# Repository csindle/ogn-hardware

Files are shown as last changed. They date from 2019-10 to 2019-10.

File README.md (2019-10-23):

# Open Glider Network Receiver Station Hardware (PipePi)

This project shows a concrete implementation of the ideas and goals on the 
[Open Glider Network](https://www.glidernet.org/) wiki page discussing how to build an 
[OGN receiver](http://wiki.glidernet.org/ogn-receiver-hardware-and-software#hardware).

Below is my current reference design which incorporates more than 12 receiver-years'
worth of experience.
The receivers are located outdoors, in the moderately harsh environment of the Western Cape,
South Africa.

#### Goals:

1. **Far range:** Minimise Radio Frequency (RF) path losses, and noise introduction.
1. **Affordable:** Few, low-cost components, and some cheap building supplies.
1. **Simple:** Largely plug-and-play components.  No RF soldering, or coax-ground loops.
1. **Reliable:**  Standards compliant electronics, DIY casing.

The CAD files for the below diagrams are in their respective directories.

All dimensions are in millimetres.

# Bill of Materials

Item   | Description
---: | :---
Raspberry Pi | Version 3B, 3B+, or 4
FlightAware USB	| With built-in Low Noise Amplifier (LNA), but without the 1090 MHz bandpass filter
SD card | 8 GB, or greater
Backplane | See description below
Outdoor Enclosure | See description below
PoE splitter | Active, standards compliant (IEEE 802.3af)
Antenna-to-SDR adaptor | Male N-type to male SMA adaptor
Antenna | 868 Mhz depending on your location. Available online from China.
PoE injector | Active, standards compliant (IEEE 802.3af)
Ethernet cable | Rated for outdoor usage
Cable/zip-ties | width less than 5 mm

# Backplane

##### Material: ~3 mm plywood, with ~5 mm drilled holes.

The Raspberry Pi and other components are mounted upon the backplane.
It provides strain relief, and durability due to its rigidity.

One may be tempted to drill only those holes that are immediately required, but in my experience,
a re-configurable backplane, decoupled from the immediate components choice, is a better long-term solution.
For example, the Raspberry Pi 4 upgrade swapped the USB and Ethernet positions,
implying that the lower holes [only!] now need to be mirrored.
A drill shouldn't be needed to swap out a RPi3 for a RPi4.

Other rigid, non-conductive material may be used instead of wood.

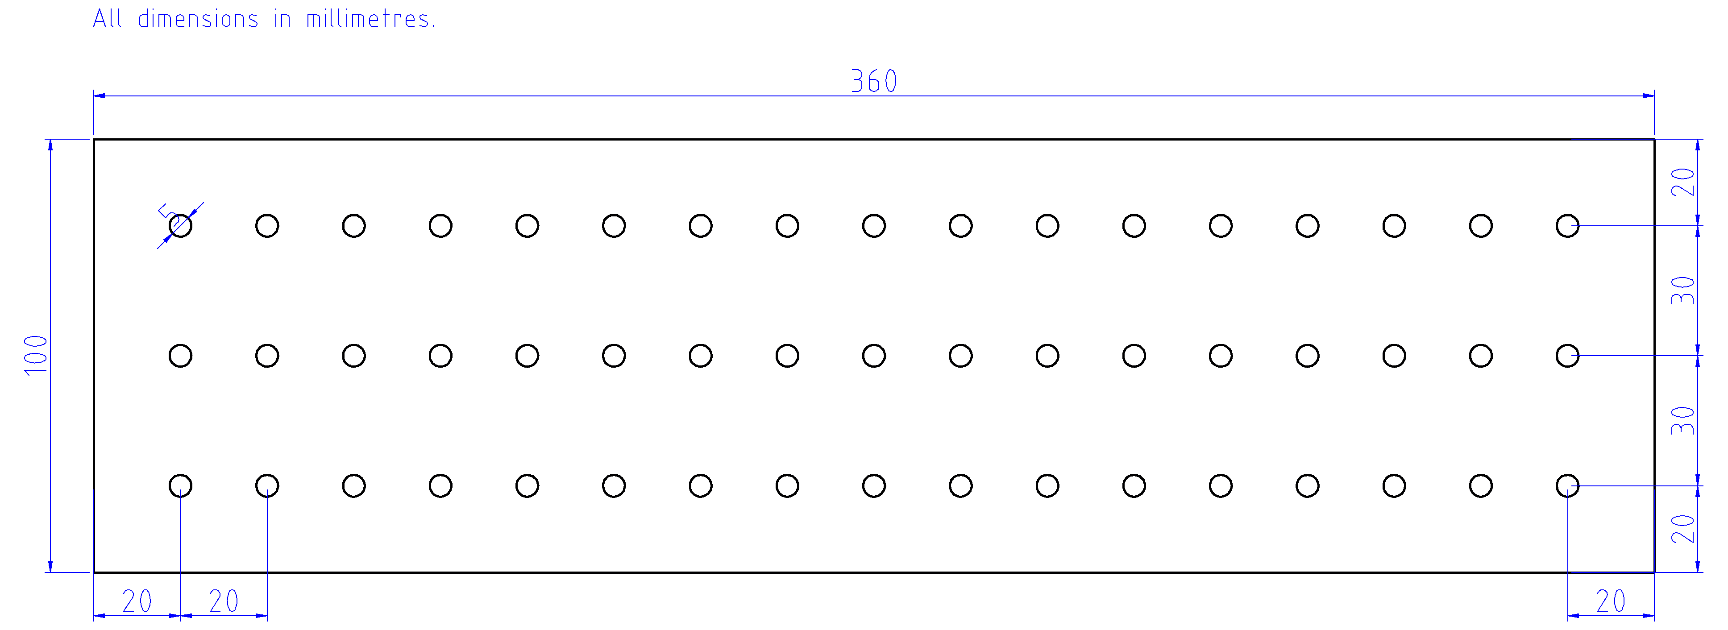
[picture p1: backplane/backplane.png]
Wooden backplane


# Weather-proof Outdoor Enclosure
##### Material: white, 110 mm PVC pipe, and matching commercial, off-the-shelf plumbing end-cap.

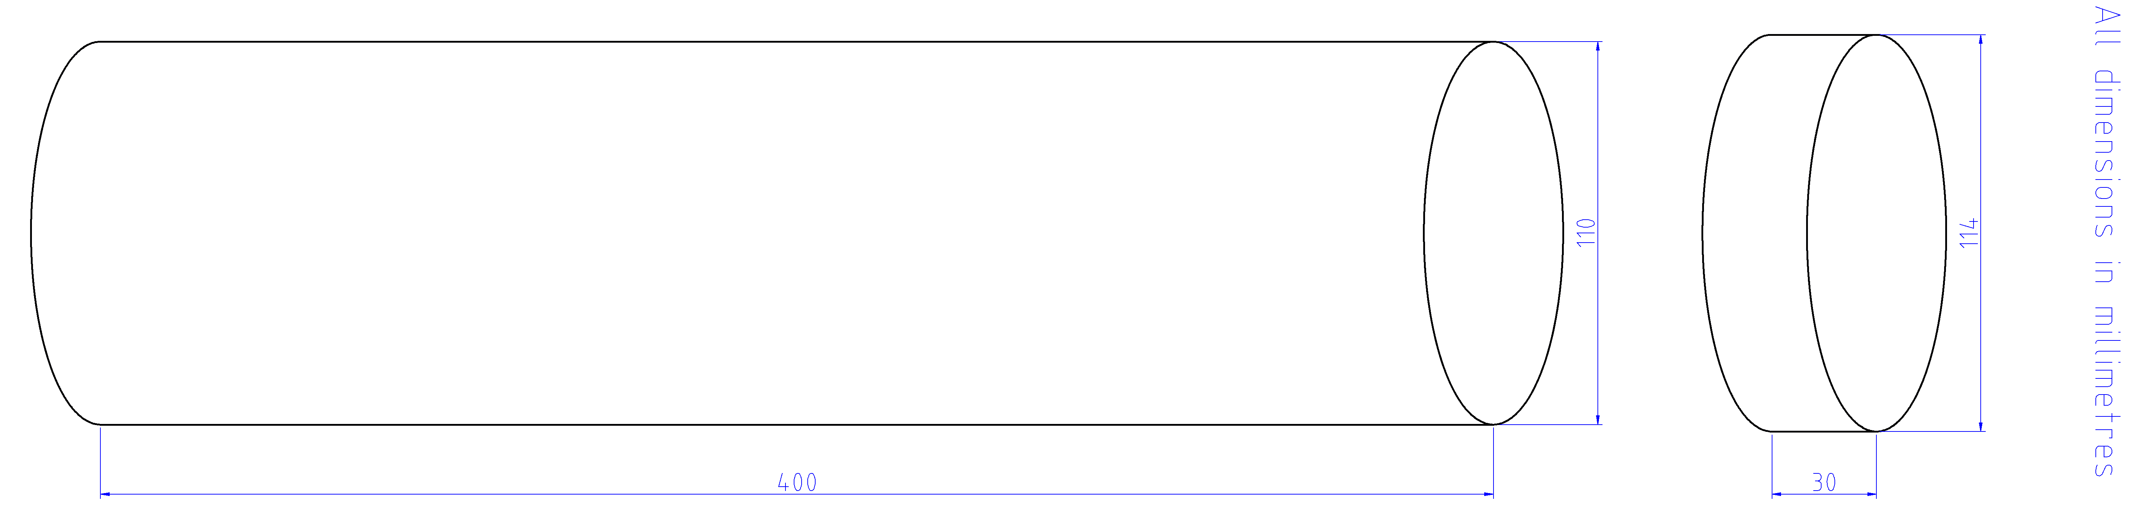
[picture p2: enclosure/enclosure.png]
PVC pipe enclosure


Unless the end-cap is holding up the enclosure (on, say, an internal mounting),
it stays on tightly enough without adhesive being required, which makes future upgrades easier.

# Assembly

Raspberry Pi cable-tied to backplane and installed within the enclosure.

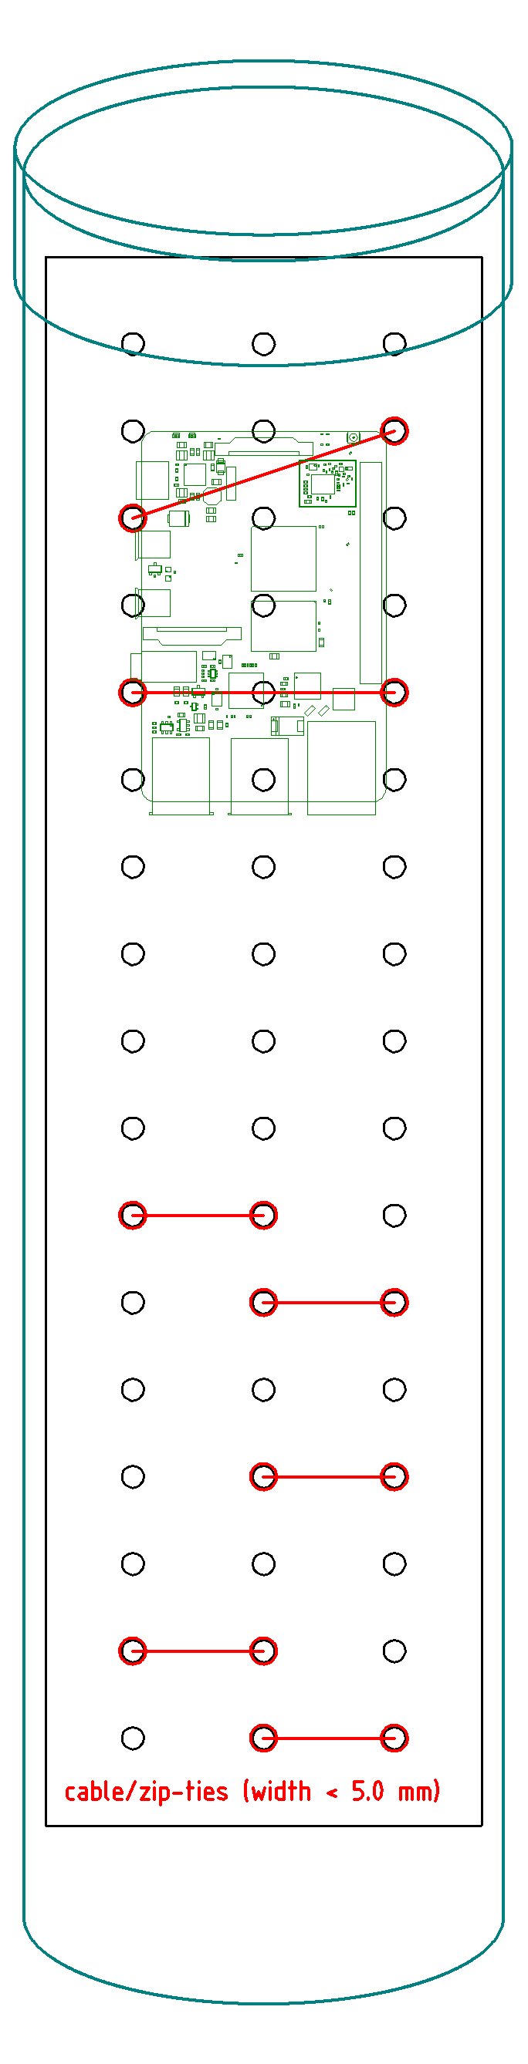
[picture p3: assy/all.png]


Parts not shown in CAD drawing:

* PoE splitter, with 5V USB power output (RPi4 requires Type-C plug, the rest, micro-USB)
* Ethernet cable
* FlightAware USB RTL SDR
* Male N-type to male SMA connector (one piece, not a pig-tail)
* Antenna cable

# Receiver's Internal Components
Assembling and securing the internal components.
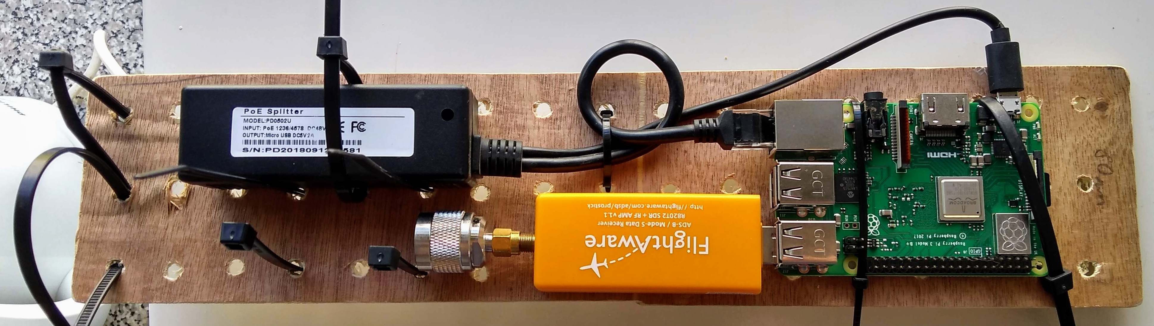
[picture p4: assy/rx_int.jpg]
Receiver components


# Receiver Mounted
Final installation, as high up as possible.
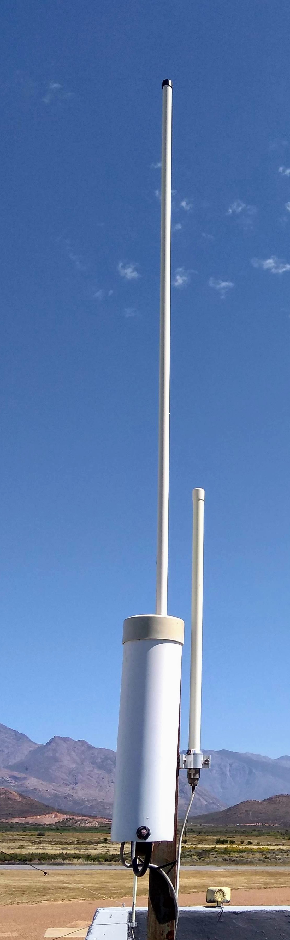
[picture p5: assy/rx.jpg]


# Thanks

To [PicoJump](https://www.picojump.com) for providing remote SSH and HTTP access, and up-time monitoring.

Please contact me, or open an issue, if you have any questions or suggestions.

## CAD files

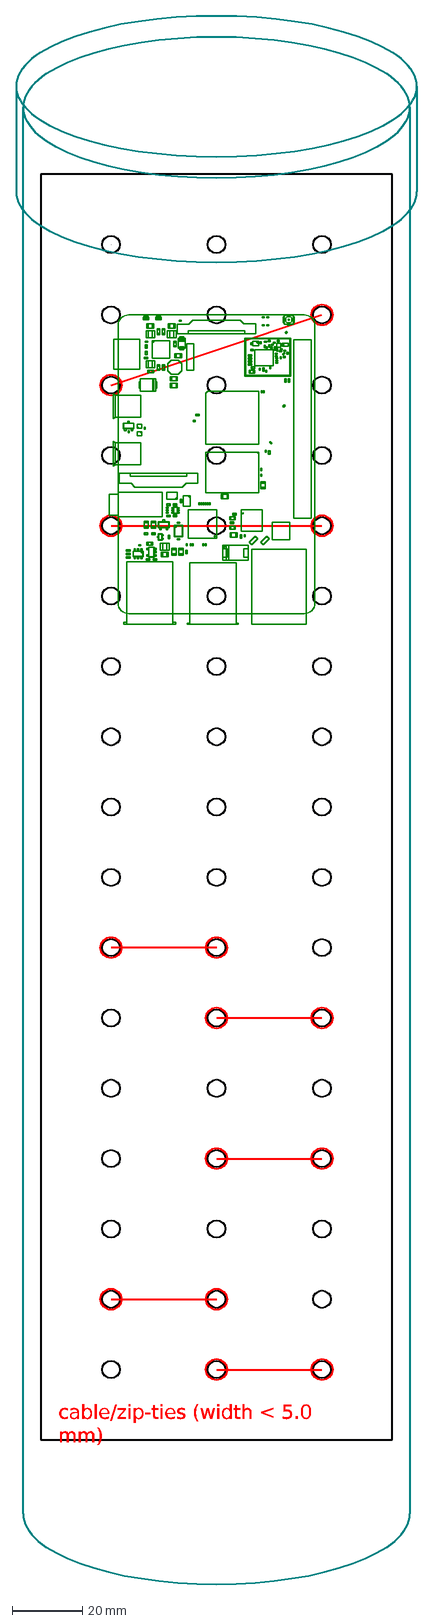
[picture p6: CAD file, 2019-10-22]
assy/all.dxf
cable/zip-ties (width < 5.0 mm)

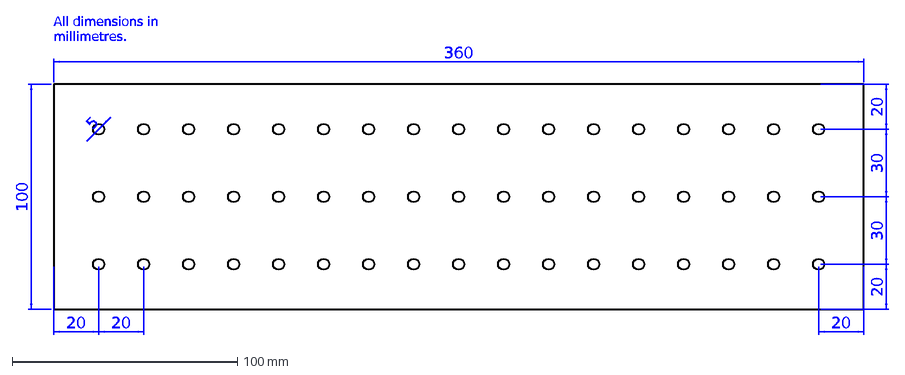
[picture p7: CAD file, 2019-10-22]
backplane/backplane.dxf
360
100
20
30
5
All dimensions in millimetres.

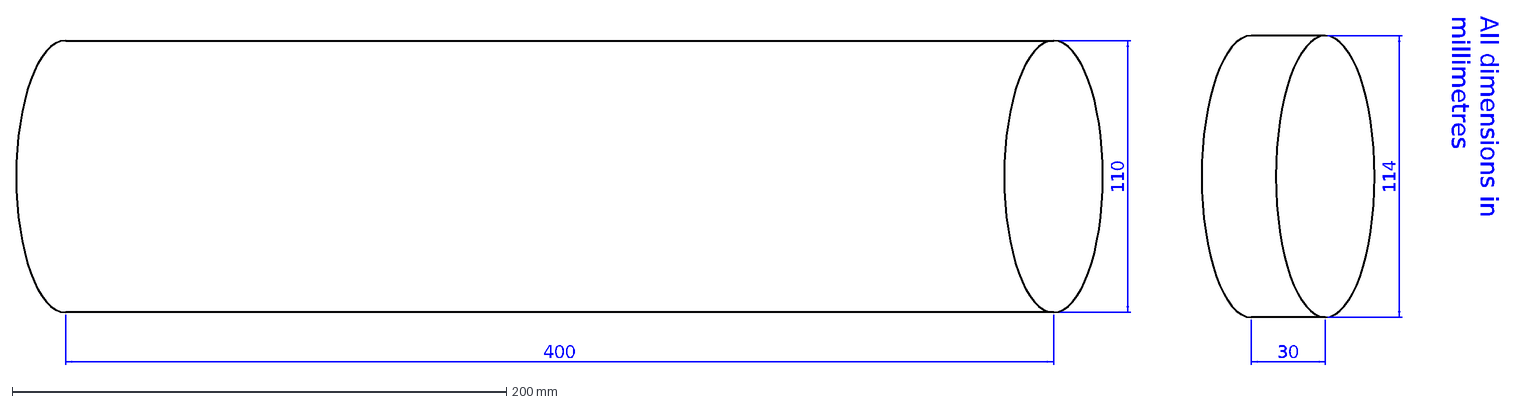
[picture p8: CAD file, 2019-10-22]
enclosure/enclosure.dxf
110
30
114
400
All dimensions in millimetres

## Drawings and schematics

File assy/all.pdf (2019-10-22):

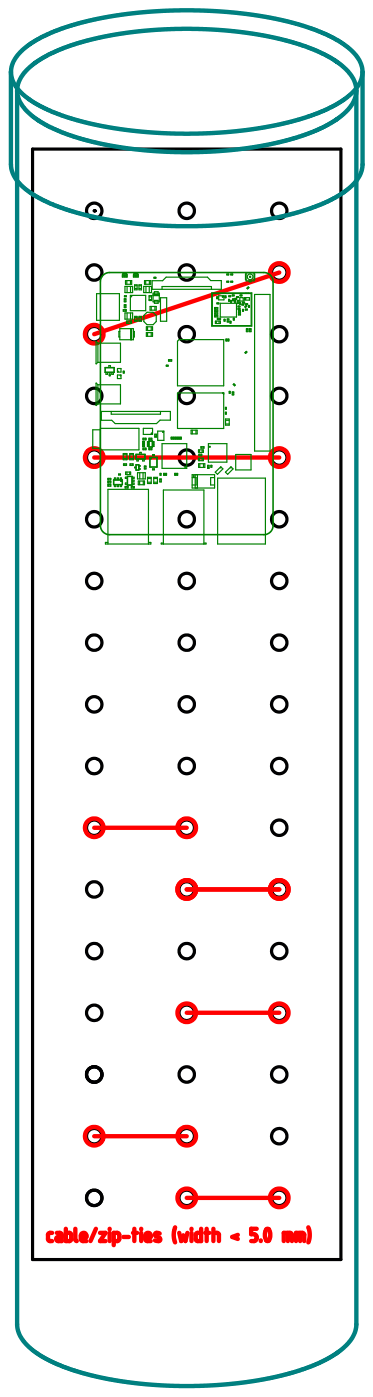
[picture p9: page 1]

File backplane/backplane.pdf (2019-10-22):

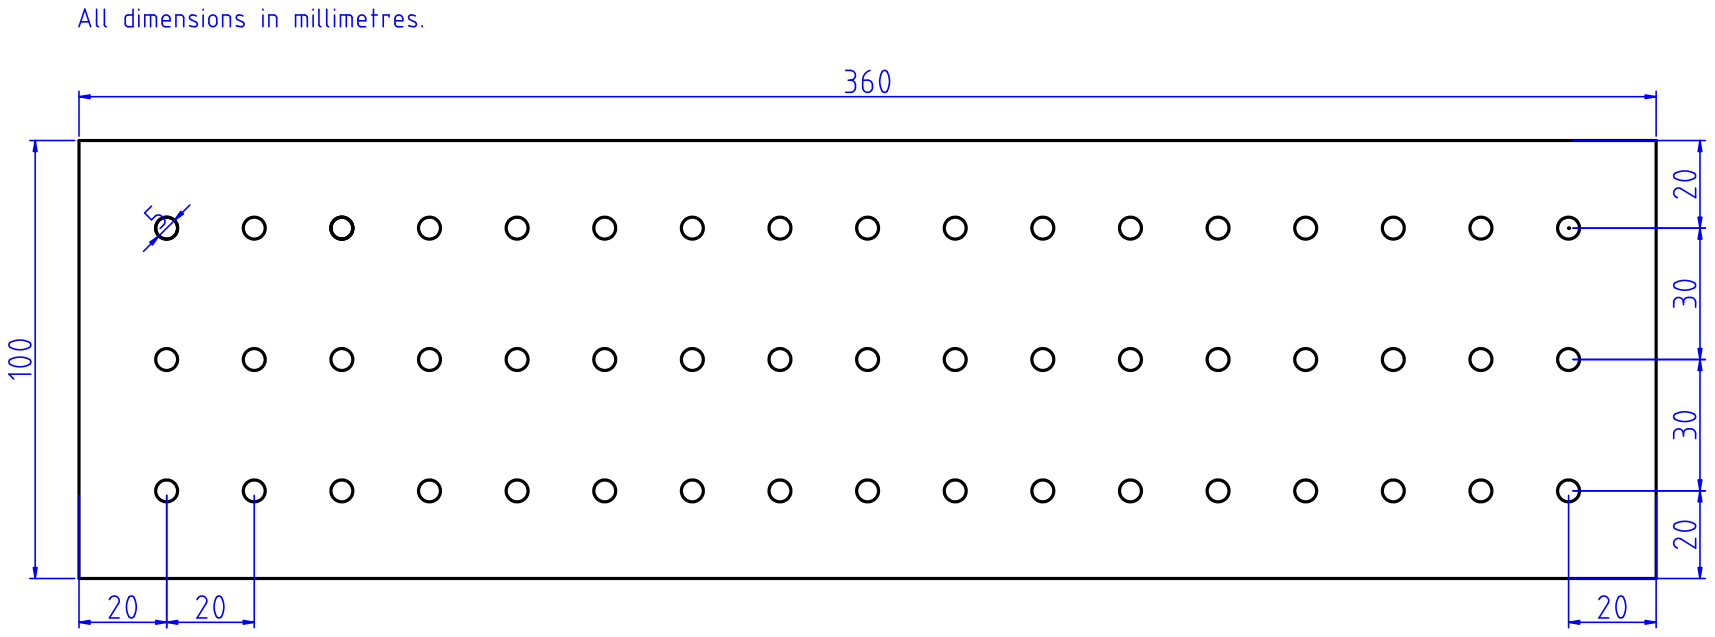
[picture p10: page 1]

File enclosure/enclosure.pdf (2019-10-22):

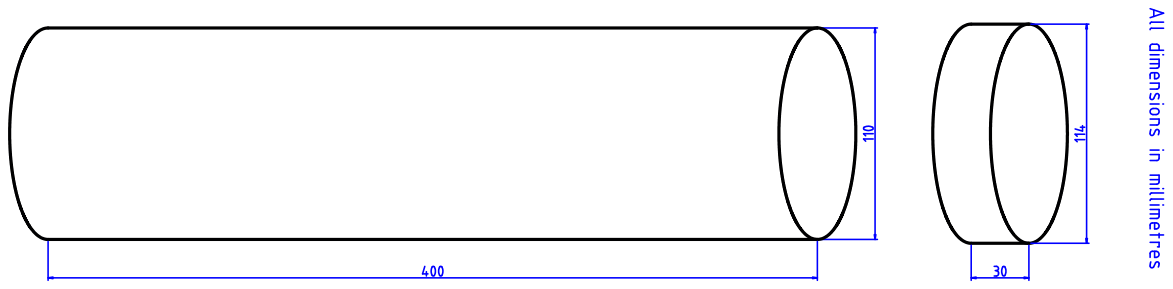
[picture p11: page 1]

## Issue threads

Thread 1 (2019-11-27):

Closing the tube?

zodiac-maniac, 2019-11-27:
Hi, I like this construction and will copy it. Instead the flightaware Stick I will use another one maybe with pre-lna. Did you close the lower end of the tube? I am afraid of getting problems with insects if I let it open. Did you monitor the max temperature of this construction in summertime? I was thinking to put the most critical stuff to high temperature at the lowest point in the tube or just use a longer tube.
Did you try aluminum adhesive tape outside the tube to lower the temp inside and get lower hf noise inside the tube?
Kind regards

csindle, 2019-12-02:
Hi,

http://grafana.glidernet.org/d/000000001/receivers?var-receiver=FAWCS&orgId=1&from=now-1y&to=now

zodiac-maniac, 2019-12-02:
Hi, ok I made the same experiences.
Up to 90C is really hot. In Germany I don't find white tube but brown and grey, I hope they will bleach over the time. The most noise comes from the RPI itself so I use 0.2m usb extender to get the sdr away from the RPI. When using the POE splitter the noise explodes and I have to use wi-fi instead. I cross checked this by using the mounted SDR with a Windows to check the source of the noise. I will do a pipe construction to have an airflow, will look funny but I will try it and post a photo when finished, I thick it will withstand stronger winds. Regarding insects I will use flyprotection net inside the tubes...we'll see if that works ;-)

Closed 2019-12-02.

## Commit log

2019-10-22 Open Glider Network receiver station hardware CAD drawings.
    [all.dxf, backplane.dxf, enclosure.dxf]
2019-10-22 Updated BOM.
    [all.dxf]
2019-10-22 Testing image resize.
    [all.dxf]
